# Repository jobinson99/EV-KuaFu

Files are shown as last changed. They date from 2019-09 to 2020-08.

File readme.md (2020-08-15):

KuaFu - Approach to Future Electrical Vehicle 
=============================

created by: jobinson99(jobinson99@hotmail.com) 20190504

## Introduction

Kuafu is a project to produce an electrical vehicle from scratch, including the design, the component purchase, the assembling, the improvement and reformation of the present technology.

## Preparation

Design Tools: Openscad

Component List:
- Front axle
- Rear axle
- motor controller
- wheel
- shock absorber: steel plate
- route
- brake: dish and drum
- composed switch
- backward and forward switch
- accelerator
- meter
- transformer: 48v/60v to 12v
- snail horn 
- backward alert horn
- charger
- hanger
- headlight
- backlight
- direction light
- lock
- water blower
- rearview mirror

- Steel

Assembling Tools:

- incise:
- weld:
- drill: 8mm，10mm，12mm，14mm, 17mm, 25mm
- tap:
- wrench: 8mm，10mm，12mm, 14mm, 17mm, 27mm, 30mm, 32mm

Helpful but unnecesaary:
- uplift:  windlass
- hold: vice

## The Design

v201909 design preview

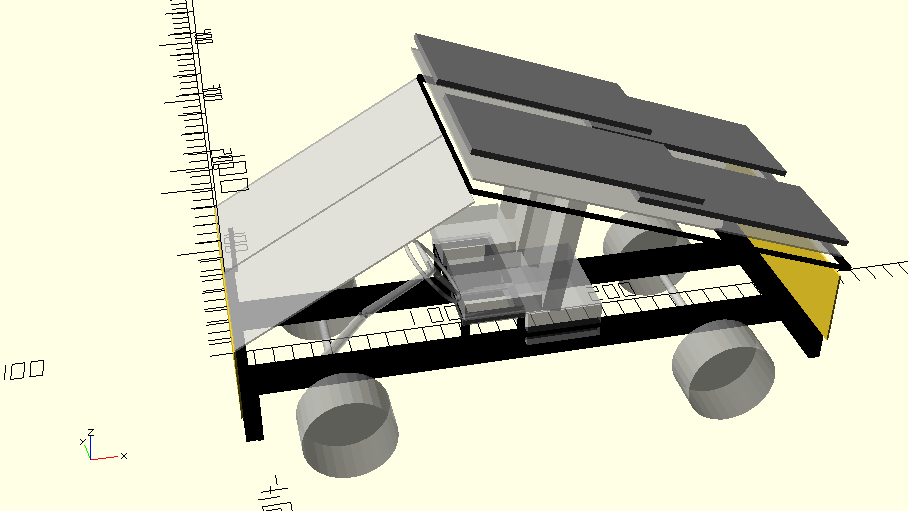
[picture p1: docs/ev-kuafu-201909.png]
v201909


v201812-20190913 design preview

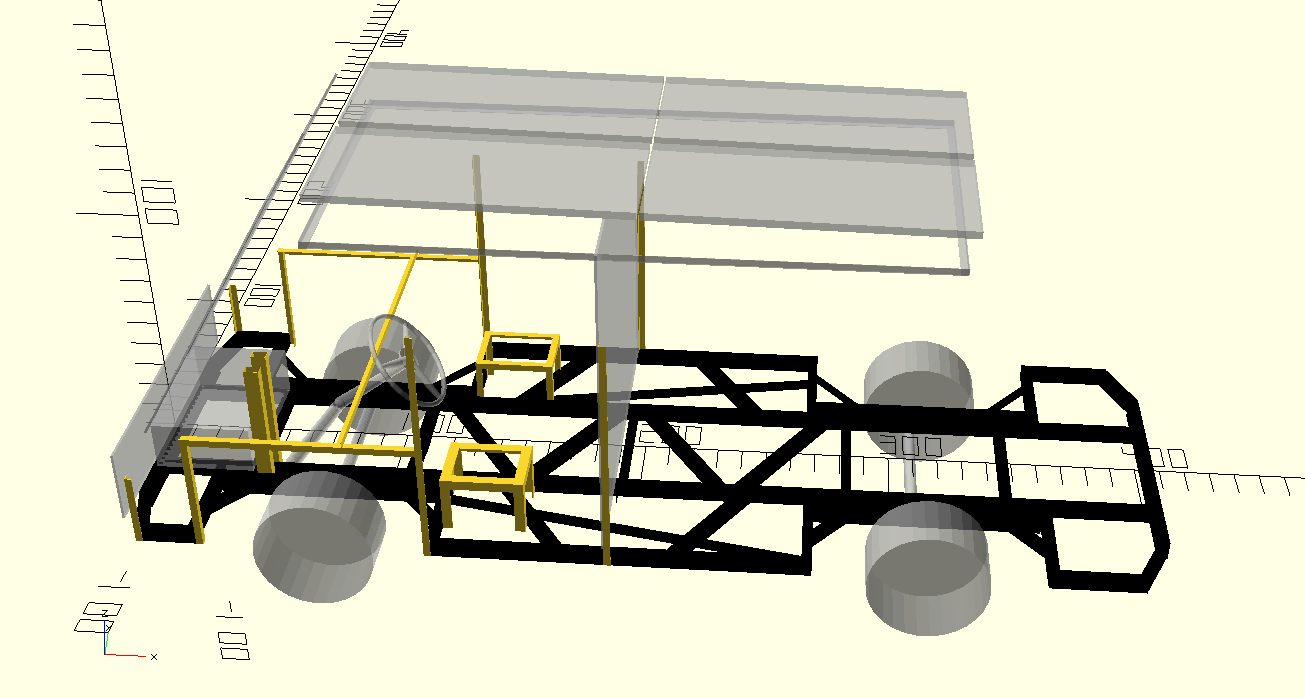
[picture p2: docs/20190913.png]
v201812-20190913


### Version

- v201812 barebone
- v20190504 add Solar Energy roof, Reforming the Skeleton.
- v201909 in order to quicker assembling, the skeleton shift to cold-formed thin-walled steel, link with screw bolt
- v201911 modify the single vehicle to main carrier with one or more trailer.
- vz backup electrical system, backup brake, thermal system, renovation of the operation system, fiber enhanced resin.

Actually, 3 version provided:
- commonly implemented, steel.
- [recommanded]main carrier with trailer, steel. Practical, easy implemented, fast assembling, cost-less, extensible.
- main carrier with trailer, fiber enhanced, for factory production.

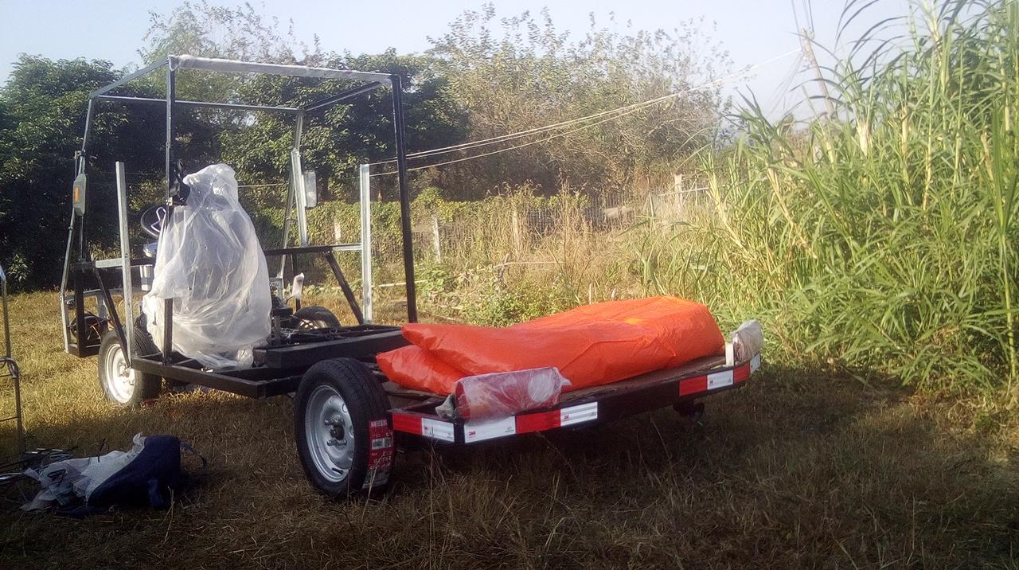
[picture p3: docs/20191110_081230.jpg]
v201911-assembling-complete


## Assembling Process

[Assembling Process](/docs/装配流程图.md)

## TODO

to be transcribed and published!

## License

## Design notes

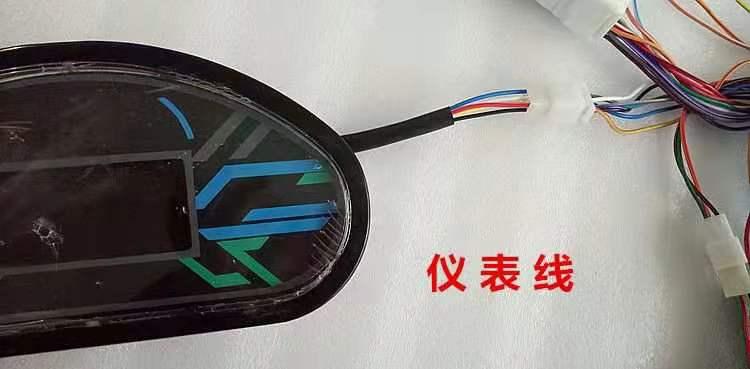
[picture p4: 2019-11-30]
docs/images/mmexport1573315327077.jpg

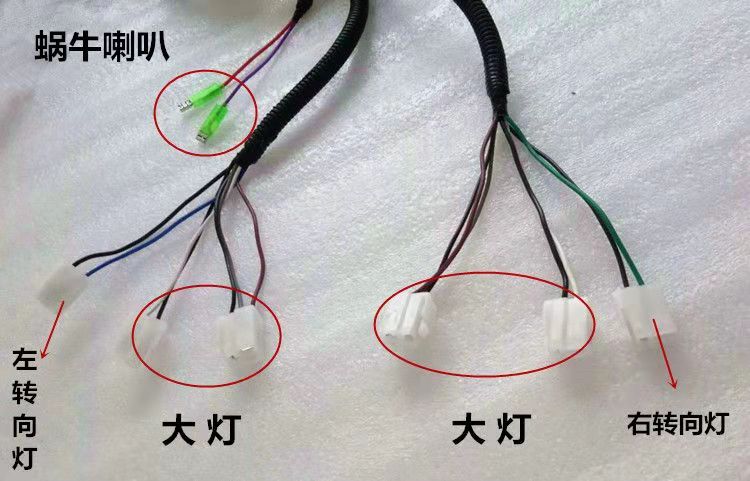
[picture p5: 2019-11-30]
docs/images/mmexport1573315391675.jpg

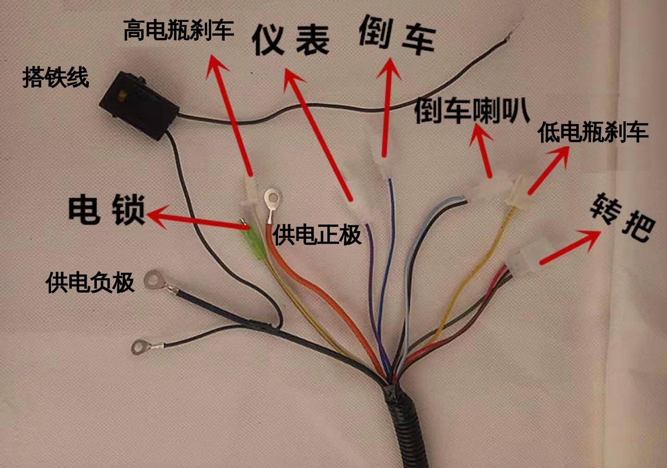
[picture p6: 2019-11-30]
docs/images/mmexport1573315280103.jpg

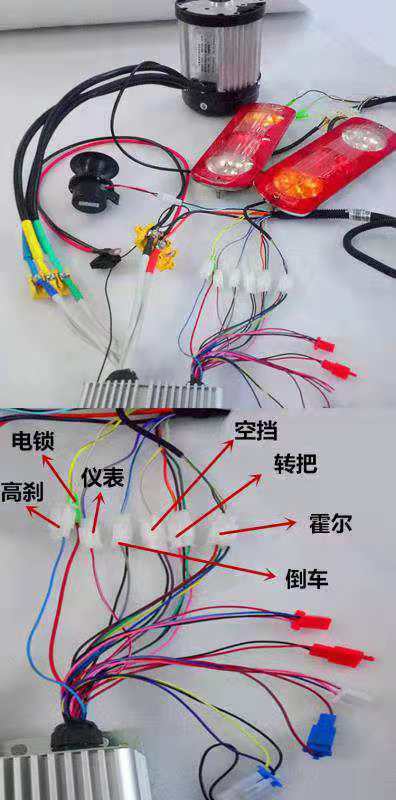
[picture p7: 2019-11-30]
docs/images/mmexport1574043584173.jpg

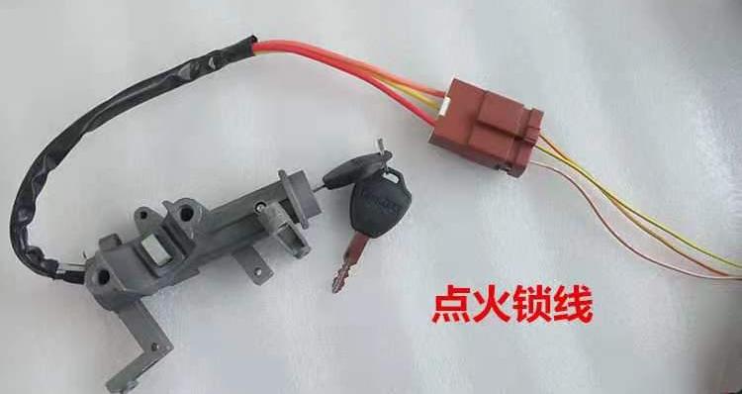
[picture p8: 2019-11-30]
docs/images/mmexport1573315397922.jpg

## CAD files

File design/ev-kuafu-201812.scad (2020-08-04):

////////////////////////////////////////////////////////
// 电动车-夸父 ev-kuafu
// Time-stamp: <此文《ev-kuafu-201812.scad》于 2020-07-21 12:23:22 被黑传说在[atlas@jobinson]上修改>
///////////////////////////////////////////////////////

use <utils/formed-material/formed-material.scad>
include <utils/material-color.scad>

module material_use () {

// 所用材料
 translate([-100,290,0]) bar_rectangle(80,40,2,10);
 translate([-100,240,0]) bar_rectangle(60,40,1.7,10);
 translate([-100,190,0])  bar_rectangle(60,40,1.2,10);

 translate([-100, 130,0]) bar_angle_equal(40,3.5,10);
 translate([-100,90,0])  bar_angle_equal(28,2.5,10);
}

module framework_bottom () {

     // 主轴
     rotate([0,90,0]) translate([0,270,40]) bar_rectangle(60,40,1.7,4000);
     rotate([0,90,0]) translate([0,-270,40]) bar_rectangle(60,40,1.7,4000);

     // 挡
     rotate([0,90,90]) translate([0,-40,-470]) bar_rectangle(80,40,2,980);
     rotate([0,90,90]) translate([0,-4080,-470]) bar_rectangle(80,40,2,980);

     // 主承架
     rotate([0,90,0]) translate([0,350,300]) bar_rectangle(80,40,2,900);
     rotate([0,90,0]) translate([0,-350,300]) bar_rectangle(80,40,2,900);
     rotate([0,90,0]) translate([0,350,2700]) bar_rectangle(80,40,2,900);
     rotate([0,90,0]) translate([0,-350,2700]) bar_rectangle(80,40,2,900);
     
// 托架
     rotate([11,90,0]) translate([90, -100,1250]) rotate([0,0,130]) bar_angle_equal(40,3.5,1500);
     rotate([-11,90,0]) translate([90, 100,1250]) rotate([0,0,130]) bar_angle_equal(40,3.5,1500);

//// 撑
     // 前
     rotate([-130,90,0]) translate([0, -615,-6]) bar_angle_equal(40,3.5,270);
     rotate([130,90,0]) translate([0, 535,-1228]) bar_angle_equal(40,3.5,270);

     rotate([-50,90,0]) translate([0, -587,-235]) bar_angle_equal(40,3.5,270);
     rotate([50,90,0]) translate([0,560,928]) bar_angle_equal(40,3.5,270);

     // 后
  
     rotate([-130,90,0]) translate([0, -2453,-1549]) bar_angle_equal(40,3.5,270);
     rotate([130,90,0]) translate([0, 2375,-2770]) bar_angle_equal(40,3.5,270);
%     rotate([-50,90,0]) translate([0, -2427,1309]) bar_angle_equal(40,3.5,270);
%     rotate([50,90,0]) translate([0, 2398,2469]) bar_angle_equal(40,3.5,270);      
     
     // 主轴 连接
     rotate([0,90,90]) translate([0,-440,-230]) bar_rectangle(60,40,1.7,500);
     rotate([0,90,90]) translate([0,-1080,-230]) bar_rectangle(60,40,1.7,500);
     rotate([0,90,90]) translate([0,-2850,-230]) bar_rectangle(60,40,1.7,500);
     rotate([0,90,90]) translate([0,-3490,-230]) bar_rectangle(60,40,1.7,500);

// 斜连
rotate([0,90,-57]) translate([0,1100,395]) bar_rectangle(60,40,1.2,620);
rotate([0,90,57]) translate([0,-1430,630]) bar_rectangle(60,40,1.2,620);     

rotate([0,90,-90]) translate([60,1900,-300]) bar_angle_equal(40,3.5,560);

rotate([0,90,-57]) translate([0,1800,847]) bar_rectangle(60,40,1.2,620);
     rotate([0,90,57]) translate([0,-2160,1105]) bar_rectangle(60,40,1.2,620);
     
     // 中部外翼
     rotate([0,90,0]) translate([0,710,1200]) bar_rectangle(60,40,1.7,1500);
     rotate([0,90,0]) translate([0,-710,1200]) bar_rectangle(60,40,1.7,1500);

     rotate([0,90,90]) translate([0,-1240,310]) bar_rectangle(60,40,1.7,400);
     rotate([0,90,90]) translate([0,-1240,-670]) bar_rectangle(60,40,1.7,400);
     rotate([0,90,90]) translate([0,-2700,310]) bar_rectangle(60,40,1.7,400);
     rotate([0,90,90]) translate([0,-2700,-670]) bar_rectangle(60,40,1.7,400);
// 中部外翼斜连接
rotate([0,90,57]) translate([0,-1050,1025]) bar_rectangle(60,40,1.2,500);
rotate([0,90,-57]) translate([0,2200,585]) bar_rectangle(60,40,1.2,500);
rotate([0,90,-57]) translate([0,1050,1005]) bar_rectangle(60,40,1.2,500);
     rotate([0,90,57]) translate([0,-2200,605]) bar_rectangle(60,40,1.2,500);
     
// 前后承架
    rotate([0,90,90]) translate([0,-300,310]) bar_rectangle(60,40,1.7,400);
    rotate([0,90,90]) translate([0,-300,-670]) bar_rectangle(60,40,1.7,400);
     rotate([0,90,90]) translate([0,-3640,310]) bar_rectangle(60,40,1.7,400);
     rotate([0,90,90]) translate([0,-3640,-670]) bar_rectangle(60,40,1.7,400);
 
// 前架
 rotate([0,90,0]) translate([0,710,60])  bar_rectangle(60,40,1.2,240);
 rotate([0,90,0]) translate([0,-710,60])  bar_rectangle(60,40,1.2,240);

 rotate([0,90,76]) translate([0,83,494])  bar_rectangle(60,40,1.2,250); 
 rotate([0,90,-76]) translate([0,-114,455])  bar_rectangle(60,40,1.2,250);
 
// 后架
 rotate([0,90,0]) translate([0,710,3600])  bar_rectangle(60,40,1.2,370);
 rotate([0,90,0]) translate([0,-710,3600])  bar_rectangle(60,40,1.2,370);

  rotate([0,90,-65]) translate([0,3873,1012])  bar_rectangle(60,40,1.2,250); 
  rotate([0,90,65]) translate([0,-3897,1048])  bar_rectangle(60,40,1.2,250);
 
}

// 车身
module framework_body(){
     // 前架
      translate([55,752,-60]) rotate([0,0,-90]) bar_angle_equal(28,2.5,300);
     translate([55,-712,-60])  bar_angle_equal(28,2.5,300);

     translate([325,752,-60]) rotate([0,0,180]) bar_angle_equal(28,2.5,500);
     translate([325,-712,-60]) rotate([0,0,90]) bar_angle_equal(28,2.5,500);

     // 部件固定
     translate([440,-200,-60])  bar_rectangle(60,40,1.2,550);
     translate([440,-310,-60])  bar_rectangle(60,40,1.2,550);
     
rotate([0,90,0]) translate([-440,753,300]) rotate([0,0,-90]) bar_angle_equal(28,2.5,900);
rotate([0,90,0]) translate([-440,-713,300]) bar_angle_equal(28,2.5,900);
     
rotate([0,90,90]) translate([-440,-925,-720]) rotate([0,0,90])
     bar_angle_equal(28,2.5,1470);

module seat () {
// 座椅底架
// 驾驶座
     rotate([90,90,0]) translate([-230,0,0]) bar_angle_equal(40,3.5,260);
     rotate([0,90,0]) translate([-230,0,0]) rotate([0,0,-90]) bar_angle_equal(40,3.5,330);
     rotate([90,90,0]) translate([-230,330,0]) rotate([0,0,-90]) bar_angle_equal(40,3.5,260);
     rotate([0,90,0]) translate([-230,-260,0]) bar_angle_equal(40,3.5,330);

// 椅腿
     translate([0,0,0]) rotate([0,0,-90]) bar_angle_equal(40,3.5,230);
     translate([330,0,0]) rotate([0,0,180]) bar_angle_equal(40,3.5,230);
     translate([0,-260,0]) bar_angle_equal(40,3.5,230);
     translate([330,-260,0]) rotate([0,0,90]) bar_angle_equal(40,3.5,230);
}

module seat_sub () {
// 副座
     rotate([90,90,0]) translate([-230,0,0]) bar_angle_equal(28,2.5,260);
     rotate([0,90,0]) translate([-230,0,0]) rotate([0,0,-90]) bar_angle_equal(28,2.5,330);
     rotate([90,90,0]) translate([-230,330,0]) rotate([0,0,-90])  bar_angle_equal(28,2.5,260);
     rotate([0,90,0]) translate([-230,-260,0]) bar_angle_equal(28,2.5,330);

// 椅腿
     translate([0,0,0]) rotate([0,0,-90]) bar_angle_equal(28,2.5,230);
     translate([330,0,0]) rotate([0,0,180]) bar_angle_equal(28,2.5,230);
     translate([0,-260,0]) bar_angle_equal(28,2.5,230);
     translate([330,-260,0]) rotate([0,0,90]) bar_angle_equal(28,2.5,230);
}

translate([1240, -270, -60]) seat ();
translate([1240, 570, -60]) seat_sub ();

// 车厢前柱
     translate([1198,752,-60]) rotate([0,0,-90]) bar_angle_equal(28,2.5,1000);
     translate([1198,-712,-60]) bar_angle_equal(28,2.5,1000);

     // 车箱后柱
     translate([1900,752,-60]) rotate([0,0,-90]) bar_angle_equal(28,2.5,1000);
     translate([1900,-712,-60]) bar_angle_equal(28,2.5,1000);
     
}

// 车顶棚
module framework_top() {
      rotate([0,90,90]) translate([0,0,100])  rotate([0,0,180])  bar_angle_equal(28,2.5,1200);
      rotate([0,90,0]) translate([0,1300,0])  rotate([0,0,180])  bar_angle_equal(28,2.5,2400);
      rotate([0,90,90]) translate([0,-2400,100])  rotate([0,0,90])  bar_angle_equal(28,2.5,1200);
      rotate([0,90,0]) translate([0,100,0]) rotate([0,0,90]) bar_angle_equal(28,2.5,2400);
}


// 外壳
module shell() {
     // 车前盖
     rotate([0,-90,0]) translate([0,-650,0]) cube([300,1300,10]);
     
     // 车前窗

     rotate([0,-60,0]) translate([350,0,80]) cube([1200,550,10]);
     rotate([0,-60,0]) translate([350,-550,80]) cube([1200,550,10]);
     
     // 车门

     
     // 太阳能电板
     rotate([0,1,0]) translate([800,-540,1400]) cube([1200,550,30]);
     rotate([0,1,0]) translate([800,60,1400]) cube([1200,550,30]);
     rotate([0,1,0]) translate([2010,-540,1400]) cube([1200,550,30]);
     rotate([0,1,0]) translate([2010,60,1400]) cube([1200,550,30]);
// 车后墙
     rotate([0,-90,0]) translate([0,-690,-1900]) cube([1300,1420,10]);

}

// 部件
module parts(){
// 电池组

     module battery_pack () {
	  cube([400,600,200]);
     }
     translate([20,-300,0]) battery_pack (); 
     
     // 方向盘

     module control_wheel () {
	  rotate_extrude (angle=360) translate([200,0,0]) circle(10);
	  rotate([90,0,-30]) cylinder(200, 20,10);
	  rotate([90,0,80]) cylinder(200, 20,10);
	  rotate([90,0,-160]) cylinder(200, 20,10);
	  cylinder(10,50,50);
     }

     translate([520,-100, -100])  rotate([0,36,-18]) cylinder(450,30,25);
     translate([780,-190, 280]) rotate([0,50,-18]) cylinder(450,25,17);
     translate([1100,-295,570]) rotate([0,50,0]) control_wheel();

     // 座椅
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

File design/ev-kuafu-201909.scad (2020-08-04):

////////////////////////////////////////////////////////
// 电动车-夸父 ev-kuafu
// Time-stamp: <此文《ev-kuafu-201909.scad》于 2020-07-21 12:22:11 被黑传说在[atlas@jobinson]上修改>
///////////////////////////////////////////////////////

use <utils/formed-material/formed-material.scad>
use <utils/formed-material/formed-link.scad>
include <utils/material-color.scad>

module material_use () {
}


module framework_bottom () {
// 主轴
     translate([0,250,100]) rotate([0,90,0]) formed_C(height = 150,flange_height=60,flange_width=20, thickness = 2, length = 3000);

     translate([3000,-250,100]) rotate([180,90,0]) formed_C(height = 150,flange_height=60,flange_width=20, thickness = 2, length = 3000);


     translate([0,650,100])  rotate([90,90,0]) formed_U(height = 150,flange_height=60, thickness = 2, length = 1300);
    
     translate([3000,-650,100])  rotate([-90,90,0]) formed_U(height = 150,flange_height=60, thickness = 2, length = 1300);     
    
//  中部外翼   
    
}
module framework_front () {
     // 前架
     translate([55,752,0]) rotate([0,0,-90]) bar_angle_equal(28,2.5,300);
     translate([55,-712,0])  bar_angle_equal(28,2.5,300);    
}

module framework_back () {
     // 后架
}


// 车身
module framework_body() {

     module seat_base() {
	  // 椅腿   
	  translate([0,0,0]) rotate([0,0,-90]) bar_angle_equal(40,3.5,230);
	  translate([330,0,0]) rotate([0,0,180]) bar_angle_equal(40,3.5,230);
	  translate([0,-700,0]) bar_angle_equal(40,3.5,230);
	  translate([330,-700,0]) rotate([0,0,90]) bar_angle_equal(40,3.5,230);  
    
// 驾驶安装座    
	  translate([0,0,230]) rotate([90,90,0])bar_angle_equal(40,3.5,700);
	  translate([330,-700,230]) rotate([-90,90,0]) bar_angle_equal(40,3.5,700);
    
	  translate([330,0,230]) rotate([180,90,0]) bar_angle_equal(40,3.5,330);    
	  translate([0,-260,230]) rotate([0,90,0]) bar_angle_equal(40,3.5,330);  
    
	  translate([330,-440,230]) rotate([180,90,0]) bar_angle_equal(40,3.5,330);
	  translate([0,-700,230]) rotate([0,90,0]) bar_angle_equal(40,3.5,330); 
  
     }

     % translate([1140, 350, 60]) seat_base();

// 仪表架


     // 操作台架
     
}

// 车顶棚
module framework_top() {
     translate([0,1200,0]) rotate([90,0,0]) bar_angle_equal(28,2.5,1200);
     translate([0,1200,0]) rotate([180,-90,0]) bar_angle_equal(28,2.5,2100);
     translate([2100,1200,0]) rotate([90,-90,0]) bar_angle_equal(28,2.5,1200);
     translate([2100,0,0]) rotate([180,-90,180])bar_angle_equal(28,2.5,2100);
}


// 外壳
module shell () {
     // 车前墙
    translate([0,-650,100]) rotate([0,-90,0]) cube([400,1300,10]); 

     // 车前盖和迎风玻璃
     % translate([0,0,500]) rotate([0,-30,0]) cube([1300,650,10]);
     % translate([0,-650,500]) rotate([0,-30,0]) cube([1300,650,10]);
    
     // 车门
    
// 车后盖
     % translate([1100,-700,1300])  rotate([0,20,0]) cube([2000,1400,10]); 
    
     // 太阳能电板
    color("grey") translate([1100,-650,1400]) rotate([0,20,0]) cube([1200,550,30]);
      color("grey") translate([1100,60,1400]) rotate([0,20,0]) cube([1200,550,30]);
     color("grey") translate([1900,-650,1050]) rotate([0,20,0]) cube([1200,550,30]);
      color("grey") translate([1900,60,1050]) rotate([0,20,0]) cube([1200,550,30]);  
    
     // 车后墙
     translate([3000,-700,100]) rotate([0,-90,0]) cube([400,1400,10]);  
    
}



// 部件
module parts () {
    
     // 电池组
     module battery_pack () {
	  cube([400,600,200]);
     }
     translate([1500,-300,20]) battery_pack();    
    
     // 方向盘
     module control_wheel () {
	  rotate_extrude (angle=360) translate([200,0,0]) circle(10);
	  rotate([90,0,-30]) cylinder(200, 20,10);
	  rotate([90,0,80]) cylinder(200, 20,10);
	  rotate([90,0,-160]) cylinder(200, 20,10);
	  cylinder(10,50,50);
     }

     translate([410,-100, -100]) rotate([0,36,-18]) cylinder(450,30,25);
     translate([670,-190, 280]) rotate([0,50,-18]) cylinder(450,25,17);
     translate([1000,-295,570]) rotate([0,50,0]) control_wheel();  


     // 仪表盘
     
     // 操作台
     
     module seat () {
// 驾驶座
	  translate([0,0,230]) rotate([90,90,0])bar_angle_equal(40,3.5,260);
	  rotate([0,90,0]) translate([-230,0,0]) rotate([0,0,-90]) bar_angle_equal(40,3.5,330);
	  rotate([90,90,0]) translate([-230,330,0]) rotate([0,0,-90]) bar_angle_equal(40,3.5,260);
	  rotate([0,90,0]) translate([-230,-260,0]) bar_angle_equal(40,3.5,330);
    
	  translate([0,-300,250]) cube([400,400,100]);
	  translate([400,-300,250]) rotate([100,0,90]) cube([400,700,100]);

     }

     module seat_sub () {
// 副座
	  rotate([90,90,0]) translate([-230,0,0]) bar_angle_equal(28,2.5,260);
	  rotate([0,90,0]) translate([-230,0,0]) rotate([0,0,-90]) bar_angle_equal(28,2.5,330);
	  rotate([90,90,0]) translate([-230,330,0]) rotate([0,0,-90])  bar_angle_equal(28,2.5,260);
	  rotate([0,90,0]) translate([-230,-260,0]) bar_angle_equal(28,2.5,330);
    
	  translate([0,-300,250]) cube([400,400,100]);
	  translate([400,-300,250]) rotate([100,0,90]) cube([400,700,100]);
    
     }
   
     translate([1140, -100, 60]) seat();
     translate([1140, 400, 60]) seat_sub();     
    
// 轮子
     module wheel() {
	  rotate([90,0,0]) cylinder(240,240,240);
     }
     translate([500,710,-110]) wheel();
     translate([500,-450,-110]) wheel();
     translate([2500,710,-110]) wheel();
     translate([2500,-450,-110]) wheel();
     translate([500,640,-110]) rotate([90,0,0])cylinder(1300,25,25);
     translate([2500,640,-110])  rotate([90,0,0]) cylinder(1300,25,25);

}



/////////////////////////////////////////
// Test
////////////////////////////////////////

module framework() {
     framework_bottom();
     framework_front();
     framework_body();
     framework_back();
     translate([1100,-650,1200]) rotate([0,20,0]) framework_top();    
}

module car() {
// 比例尺 1：10
     color("black") framework();
     
     shell();

     % parts();
    
}

scale([0.1,0.1,0.1]) car();

// % scale([0.5,0.5,0.5]) material_use();

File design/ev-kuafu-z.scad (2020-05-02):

////////////////////////////////////////////////////////
// 电动车-夸父 ev-kuafu
///////////////////////////////////////////////////////

use <utils/formed-material/formed-material.scad>
include <utils/material-color.scad>

module material_use () {
    }
    
    
module framework_bottom () {
// 主轴

     
}

// 车身
module framework_body() {
     
}

// 车顶棚
module framework_top () {
     
}

// 外壳
module shell (){
     
}

// 部件
module parts(){
// 轮子
module wheel() {
	  rotate([90,0,0]) cylinder(240,240,240);
     }
     translate([750,710,-110]) wheel();
     translate([750,-450,-110]) wheel();
     translate([2150,710,-110]) wheel();
     translate([2150,-450,-110]) wheel();
     rotate([90,0,0]) translate([750,-120,-700]) cylinder(1300,25,25);
     rotate([90,0,0]) translate([2100,-120,-700]) cylinder(1300,25,25);

}

/////////////////////////////////////////
// Test
/////////////////////////////////////////

// 比例尺 1：10
scale([0.1,0.1,0.1]) framework_bottom();
framework_body();
framework_top();
shell();

% scale([0.1,0.1,0.1]) parts();

// % scale([0.5,0.5,0.5]) material_use();

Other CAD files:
design/v201812.scad
design/v201909.scad
design/vz.scad

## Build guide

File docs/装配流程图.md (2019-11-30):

# 装配流程图示

## 车架设计

## 零件装配

用钢板支架和软连接将钢板固定（此图为左前方示意图）

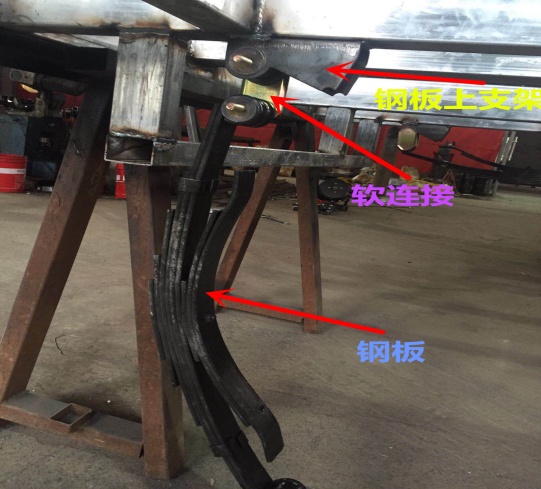
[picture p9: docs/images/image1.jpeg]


钢板的另一端，放入钢板套，用销子固定在大拉耳上

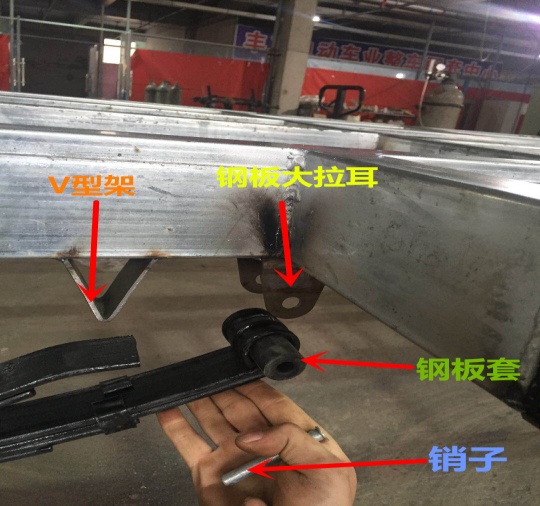
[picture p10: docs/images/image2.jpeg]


底盘的高矮决定钢板装在桥的上下

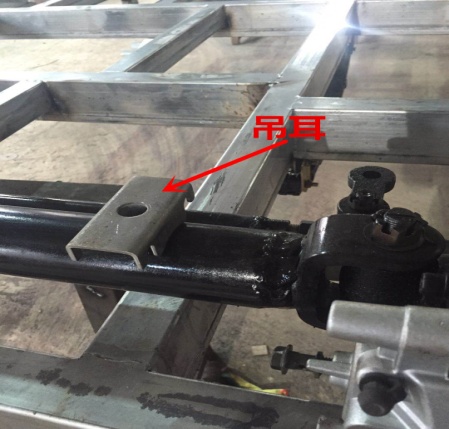
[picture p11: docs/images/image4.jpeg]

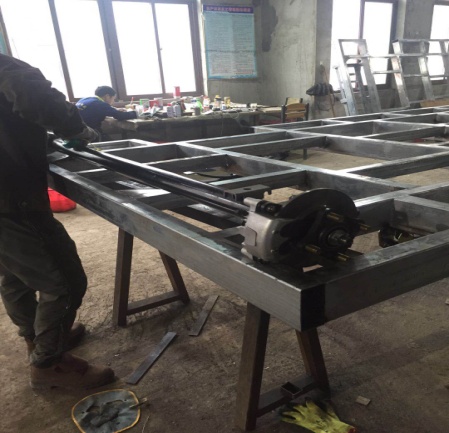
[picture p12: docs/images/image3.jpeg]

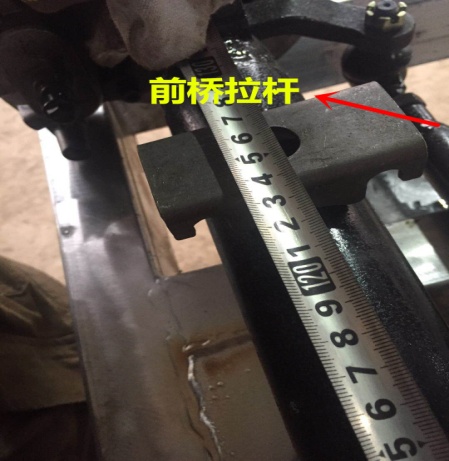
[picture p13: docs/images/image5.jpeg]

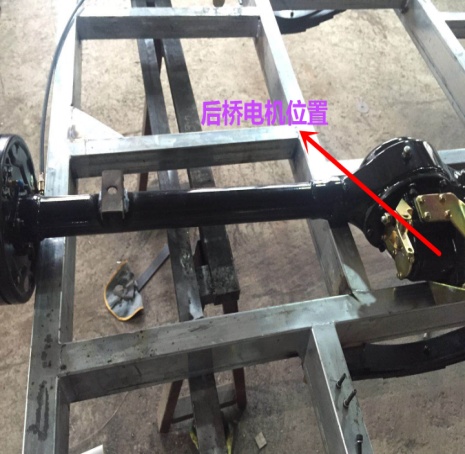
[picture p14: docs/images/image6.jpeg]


拉耳焊在桥上的距离和下面钢板铆钉到铆钉的距离要一致
底盘高矮
（注意前后桥拉耳位置，千万不要焊反了）

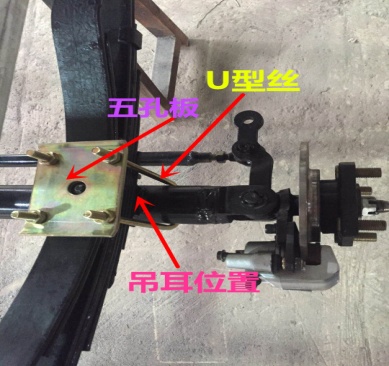
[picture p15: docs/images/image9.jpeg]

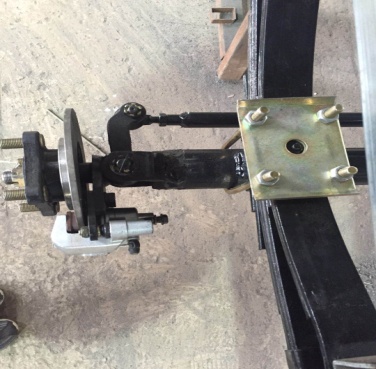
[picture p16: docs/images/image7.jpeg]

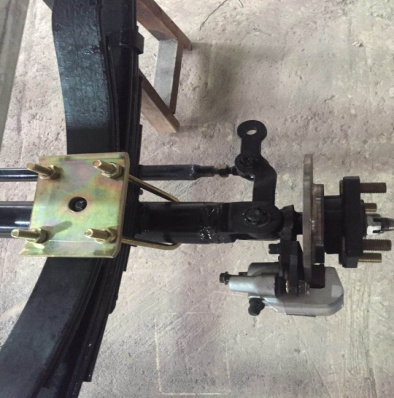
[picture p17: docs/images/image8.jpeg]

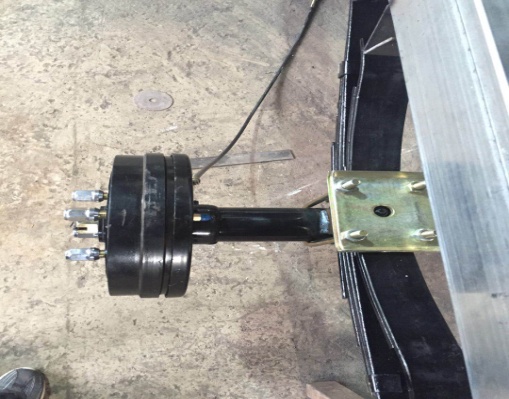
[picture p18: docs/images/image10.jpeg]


将U型丝穿过桥，用五孔板螺丝固定住

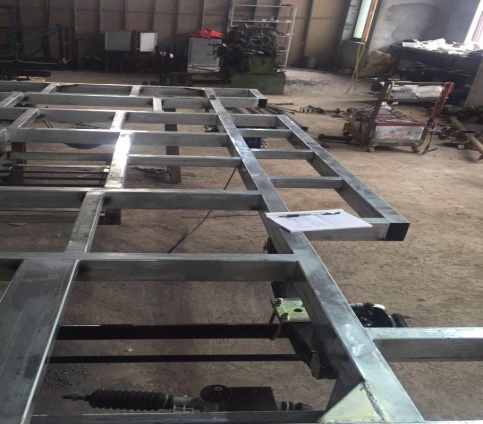
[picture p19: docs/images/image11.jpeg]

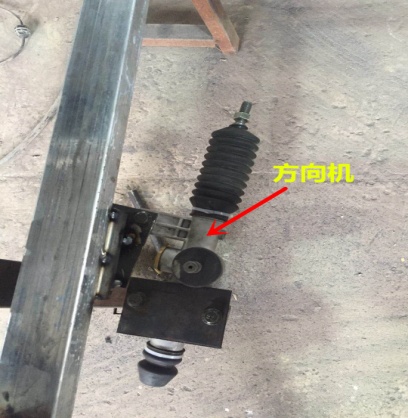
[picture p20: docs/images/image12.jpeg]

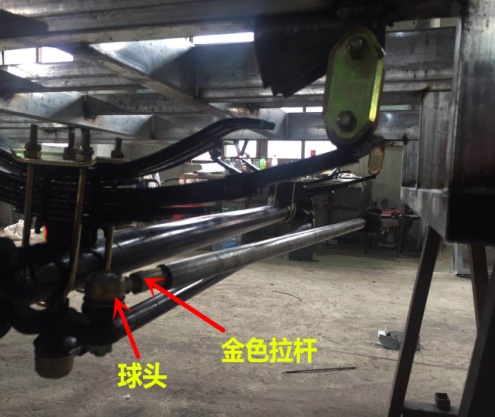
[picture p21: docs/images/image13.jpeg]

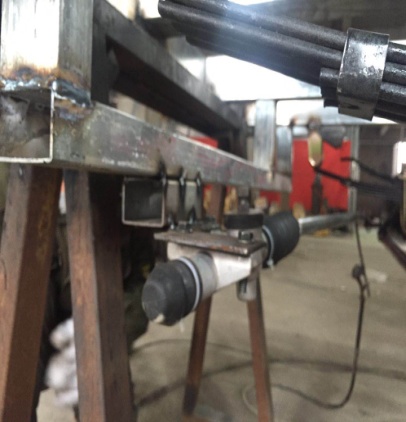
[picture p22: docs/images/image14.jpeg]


方向机斜向焊在前桥上 焊的位置要跟球头金色拉杆保持水平，以免开车时打颤

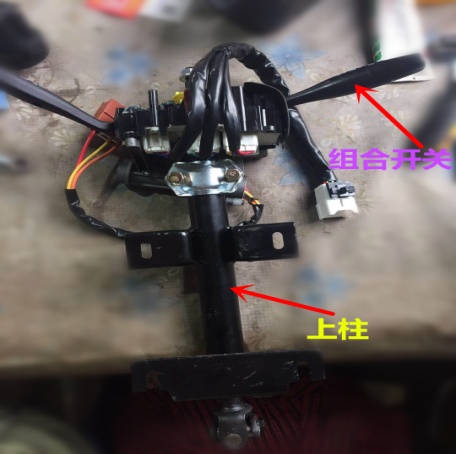
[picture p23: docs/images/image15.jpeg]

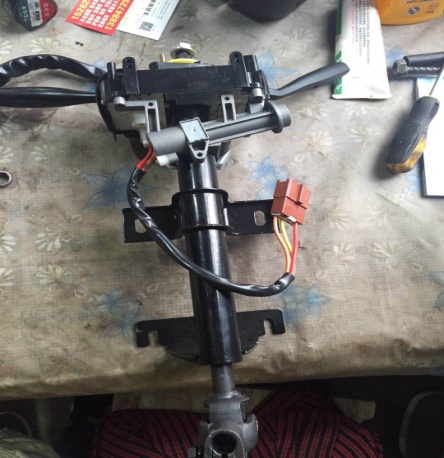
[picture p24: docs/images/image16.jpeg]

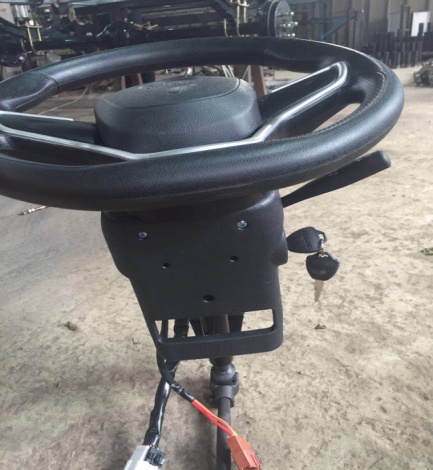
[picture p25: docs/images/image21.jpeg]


组合开关 方向盘装在一起，注意前后位置，千万不要装反了

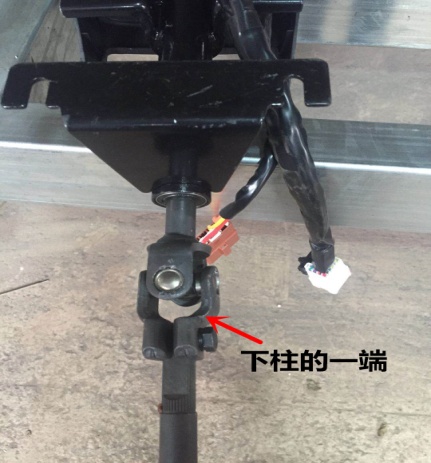
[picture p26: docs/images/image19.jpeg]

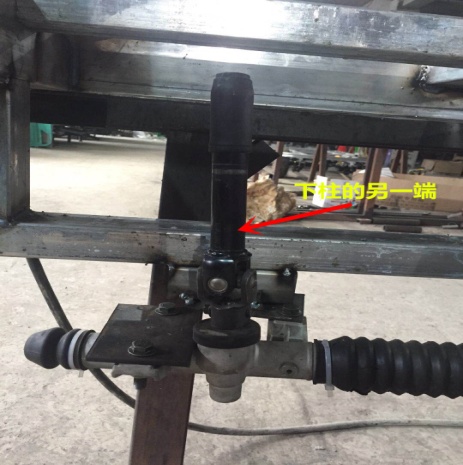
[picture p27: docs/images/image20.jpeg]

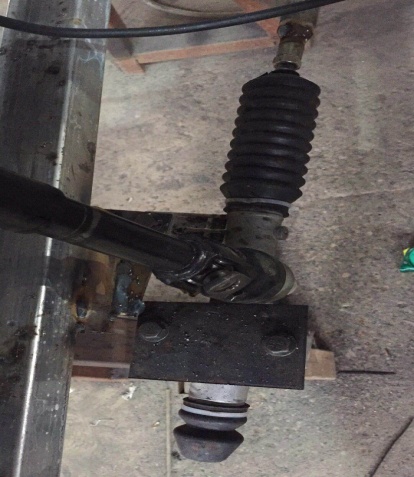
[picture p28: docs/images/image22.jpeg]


下柱的两端，一端连在上柱，另一端连在方向机

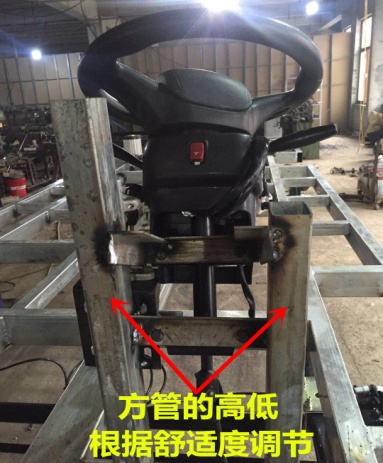
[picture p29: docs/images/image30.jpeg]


油泵，脚踏板，顶杆，断电开关装好备用，装在方向盘下面位置

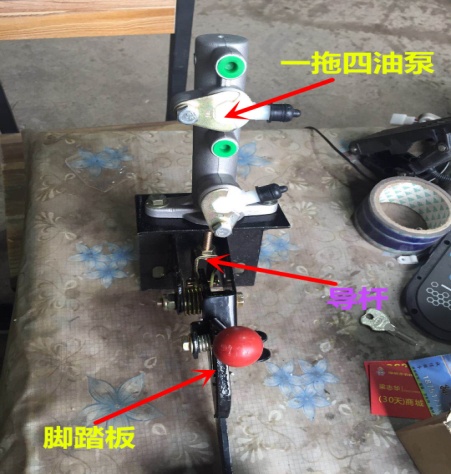
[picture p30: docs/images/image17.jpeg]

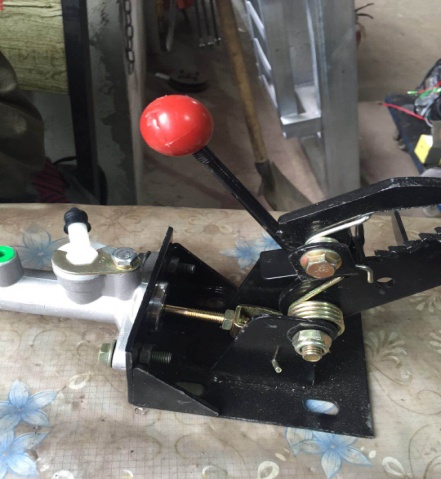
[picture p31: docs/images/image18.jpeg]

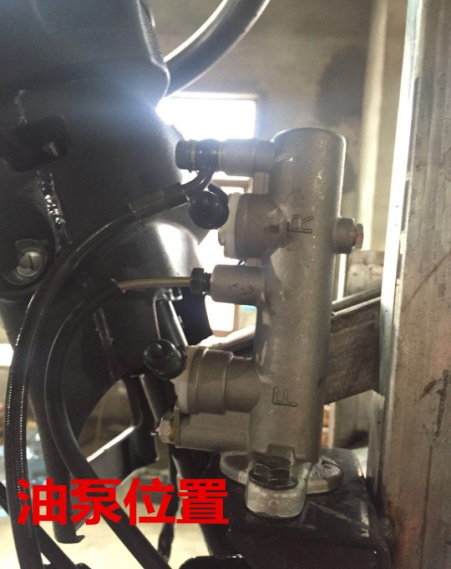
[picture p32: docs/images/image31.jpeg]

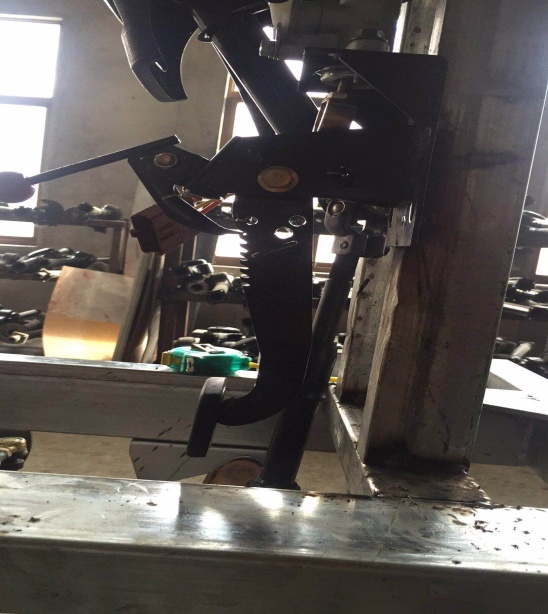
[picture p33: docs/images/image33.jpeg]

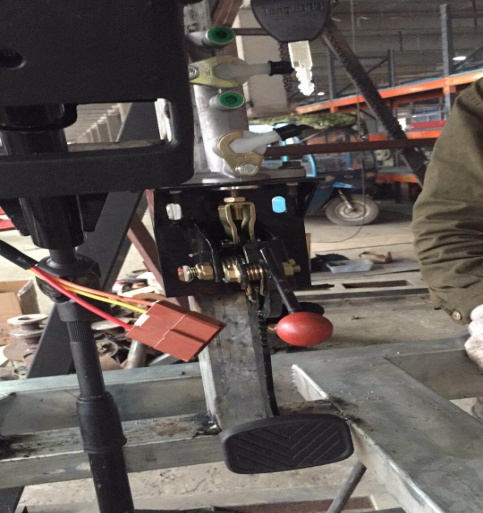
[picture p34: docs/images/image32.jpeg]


依次排列：仪表 加速器 油壶 前车喇叭 倒顺开关 转换器安装所在位置

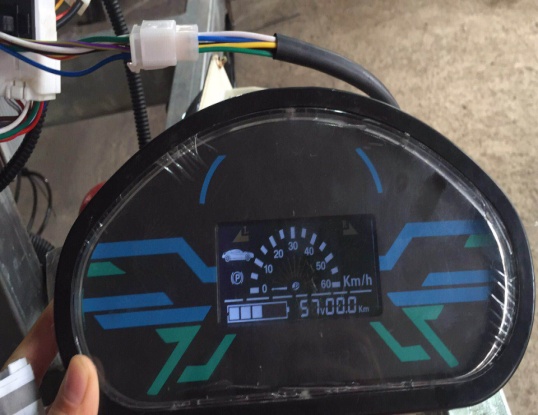
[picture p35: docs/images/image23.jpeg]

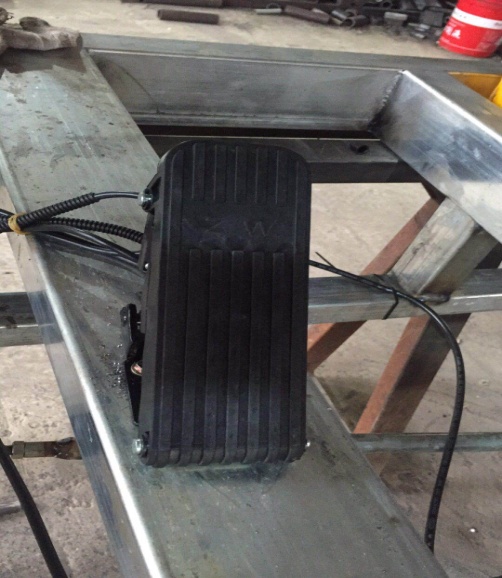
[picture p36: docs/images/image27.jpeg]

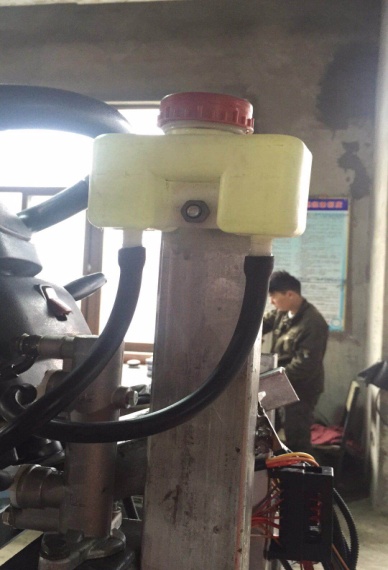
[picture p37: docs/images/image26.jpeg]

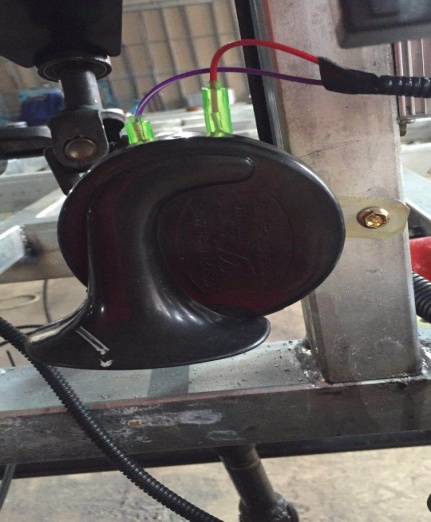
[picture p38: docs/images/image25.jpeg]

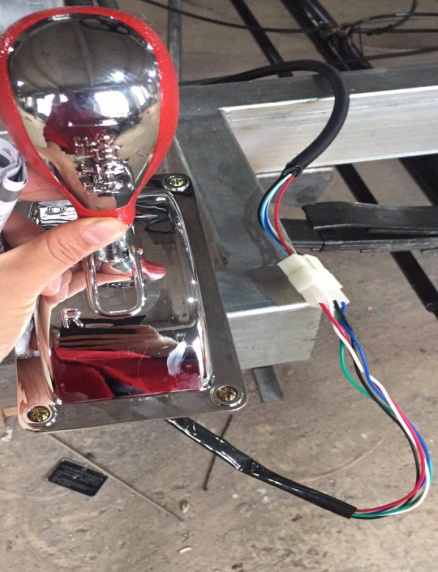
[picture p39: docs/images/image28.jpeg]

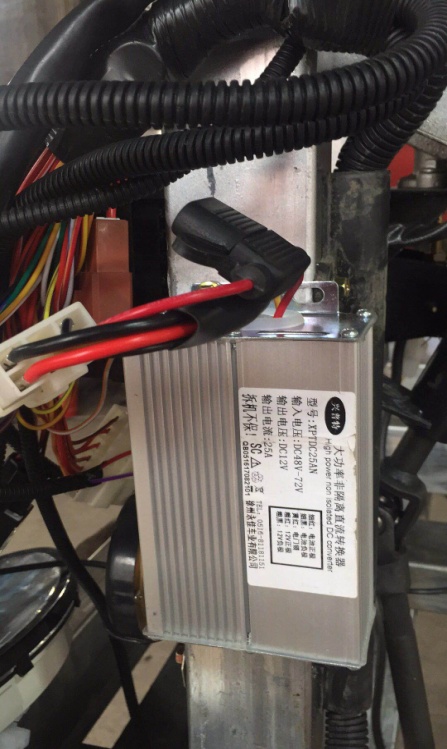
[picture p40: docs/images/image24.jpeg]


总：

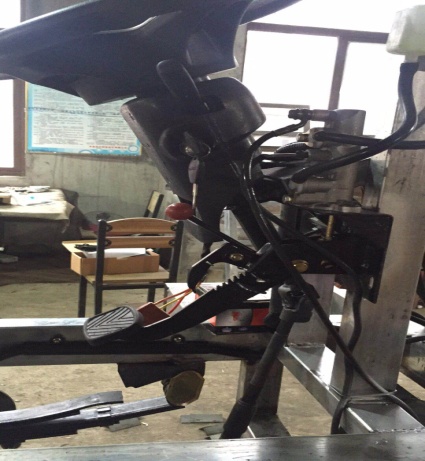
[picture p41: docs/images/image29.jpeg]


## 调试

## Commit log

2019-05-04 开天辟地
2019-05-04 改进说明
2019-05-07 添加孔钳口径数据
2019-05-10 添加零部件列表
2019-09-04 增加新版本
2019-09-13 加入v201812设计稿，加入设计稿预览截图
    [v201812.scad, v201909.scad, vz.scad]
2019-11-22 粗装完成改进说明
    [v201812.scad]
2019-11-22 粗装效果实图
2019-11-22 更新英文版
2019-11-30 加入装配流程说明
2019-11-30 更正扳手型号
2020-05-02 更改文件名为ev-kuafu-时间
    [ev-kuafu-201812.scad, ev-kuafu-201909.scad, ev-kuafu-z.scad]
2020-05-13 更新设计
    [ev-kuafu-201812.scad, ev-kuafu-201909.scad]
2020-08-15 更新说明
